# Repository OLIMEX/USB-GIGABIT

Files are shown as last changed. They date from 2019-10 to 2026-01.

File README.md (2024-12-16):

# USB-GIGABIT
USB 1.1, USB 2.0, USB 3.0 to Ethernet 10/100/1000Mbit converter

Transfer troughput is up to 950Mbits/s when connected to USB 3.0 ports and GbE network.

Using the A20 OLinuXino boards and USB 2.0 host the speed is: upload 319 Mbit, download 295 Mbit.

## Commands
    iperf3 -c 192.168.0.xxx -p 2001 -t 3
    iperf3 -c 192.168.0.xxx -p 2001 -t 3 -R
    
## Empirical Test Results

Using the commands listed above and good grade Gigabit equipment.

| Board | Upload | Download |
|---|---|---|
| PC USB 3.0 | 933 Mbits/sec | 942 Mbits/sec |
| PC USB 2.0 | 290 Mbits/sec | 312 Mbits/sec |
| A20-MICRO  | 319 Mbits/sec | 295 Mbits/sec |

# License
- Hardware is released under CERN OHL v1.2 license
- Documentation is released under CC BY-SA 4.0 license

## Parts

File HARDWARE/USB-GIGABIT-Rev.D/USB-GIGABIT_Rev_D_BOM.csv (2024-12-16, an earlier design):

Id | Designator | Footprint | Quantity | Designation | Supplier and ref
1 | C2,C3,C4,C10,C11,C14,C15,C16,C18,C19,C20,C21,C22,C24,C25,C26,C27,C1 | C_0402_5MIL_DWS | 18 | 100nF/10V/X5R /20%/0402
2 | C5 | C_0805_5MIL_DWS | 1 | 100nF/50V/Y5V/20%
3 | C6 | C_0402_5MIL_DWS | 1 | NA
4 | C7,C8 | C_0402_5MIL_DWS | 2 | 39pF/C0G/50VDC/0402
5 | C9 | C_1206_5MIL_DWS_ISO | 1 | 1nF/2000V/10%/X7R/1206
6 | C12,C17 | C_0603_5MIL_DWS | 2 | 2.2uF/X5R/6.3V/10%/0603
7 | FB1 | L_0805_5MIL_DWS | 1 | 600OHM/2A/UPZ2012E-601-2R0TF/0805
8 | R2,R3 | R_0402_5MIL_DWS | 2 | 22R/0402
9 | R4 | R_0805_5MIL_DWS | 1 | 10R/0805
10 | R5,R6,R10,R13,R14 | R_0402_5MIL_DWS | 5 | NA
11 | R9,R11 | R_0402_5MIL_DWS | 2 | 2.2K/0402
12 | U2 | SO-8 | 1 | NA(93LC46)
13 |  | LOGO_RECYCLEBIN_1 | 1
14 | U3 | QFN48-6x6mm-OLIMEX_V2 | 1 | RTL8153VC-CG
15 | X1 | Oscillator-18.432MHz-3.2x2.5mm | 1 | 25MHz/20ppm/20pF/4P/3225
16 | R1,R7 | R_0402_5MIL_DWS | 2 | 1K/0402
17 | R8 | R_0402_5MIL_DWS | 1 | 2.49K/1%/0402
18 | L1 | CD32 | 1 | 2.2uH/NRS3015T2R2MNGH
19 | R12,R15 | R_0402_5MIL_DWS | 2 | 1.1K/1%/0402
20 | U4 | SOT-23-5 | 1 | SY8089AAAC
21 | FID1,FID2 | Fiducial1x3 | 2 | Fiducial
22 | FID4,FID3 | Fiducial1x3_Paste | 2 | Fiducial
23 |  | LOGO_OPENHARDWARE_8x8 | 1
24 |  | LOGO_PBFREE | 1
25 | LAN1 | TM211Q01FM22 | 1 | TM211Q01FM22(LPJG16402AQNL)
26 | USB1 | USB3_A_MALE | 1 | USB1065
27 | Sign_CE | CE_Sign | 1 | CE_Sign
28 | Sign_Antistatic | Sign_Antistatic | 1 | Sign_Antistatic
29 | Logo_OLIMEX_TB | Logo_OLIMEX_TB | 1 | Logo_OLIMEX_TB
30 | Sign_RoHS_1 | Sign_RoHS_1 | 1 | Sign_RoHS_1

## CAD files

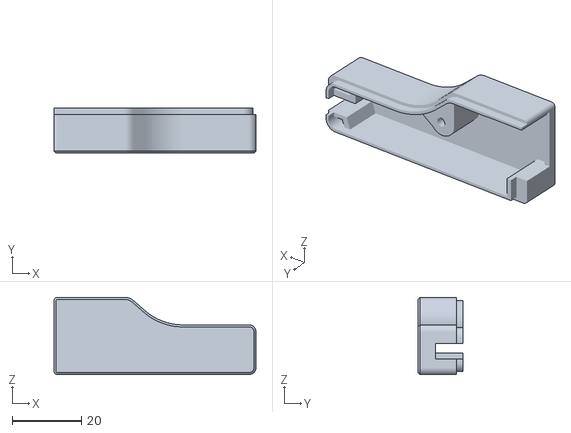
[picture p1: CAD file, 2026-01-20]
HARDWARE/BOXED-3D-design/part1.stl
58.4 x 13.1 x 22.3

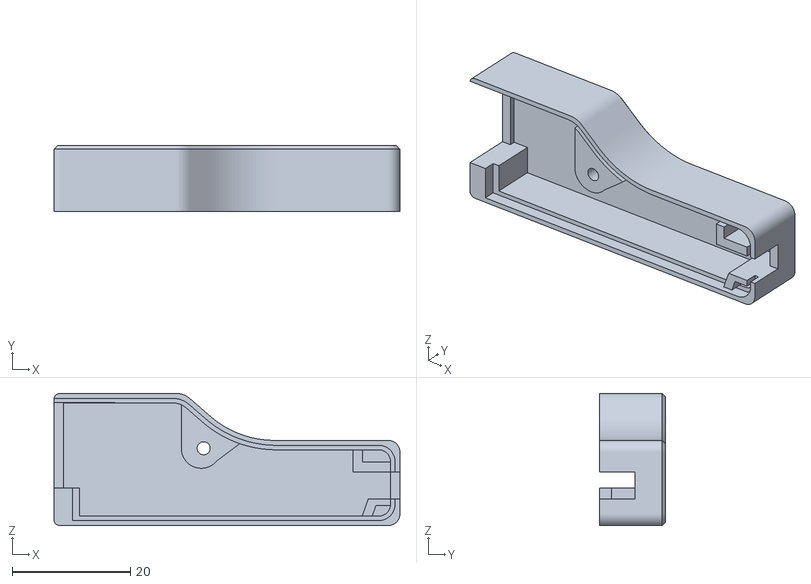
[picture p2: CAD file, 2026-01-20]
HARDWARE/BOXED-3D-design/part2.stl
58.4 x 11.1 x 22.3

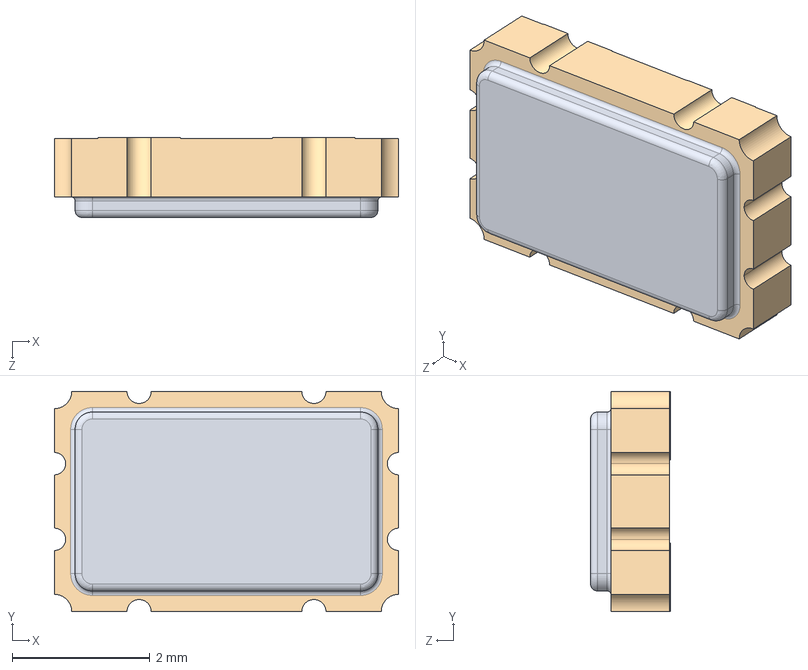
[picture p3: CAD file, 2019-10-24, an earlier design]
HARDWARE/USB-GIGABIT-Rev.C/3d/QSG5032.step
5.00 x 3.20 x 1.16 mm

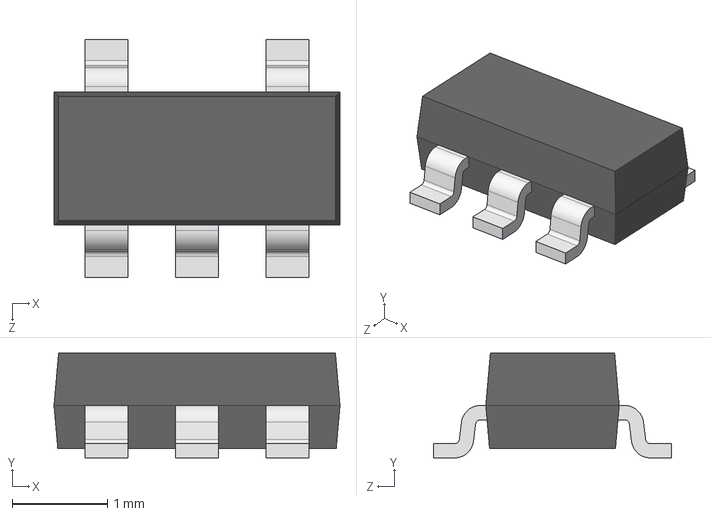
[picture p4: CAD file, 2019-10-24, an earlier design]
HARDWARE/USB-GIGABIT-Rev.C/3d/SOT-23-5.step
3.00 x 1.10 x 2.50 mm

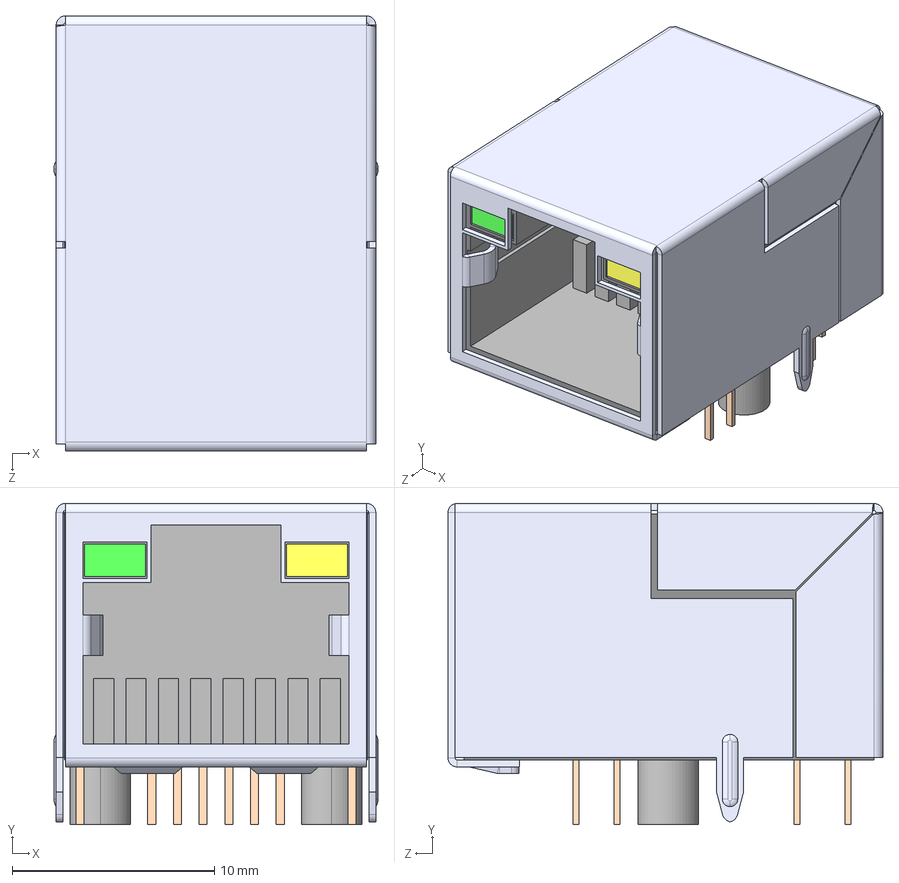
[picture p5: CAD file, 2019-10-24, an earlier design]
HARDWARE/USB-GIGABIT-Rev.C/3d/RJ45_10P_TJ3009.STEP
16.0 x 15.9 x 21.5 mm

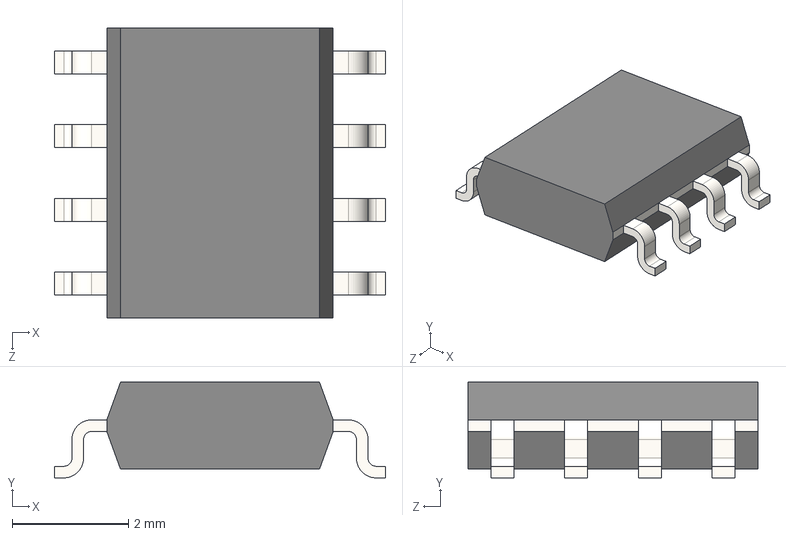
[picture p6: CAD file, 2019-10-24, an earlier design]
HARDWARE/USB-GIGABIT-Rev.C/3d/SL08.step
5.70 x 1.65 x 5.00 mm

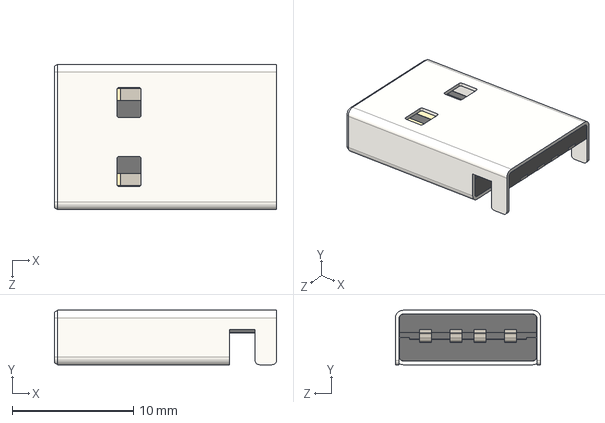
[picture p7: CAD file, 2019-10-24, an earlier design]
HARDWARE/USB-GIGABIT-Rev.C/3d/USB-A-MALE.step
18.3 x 4.50 x 12.0 mm

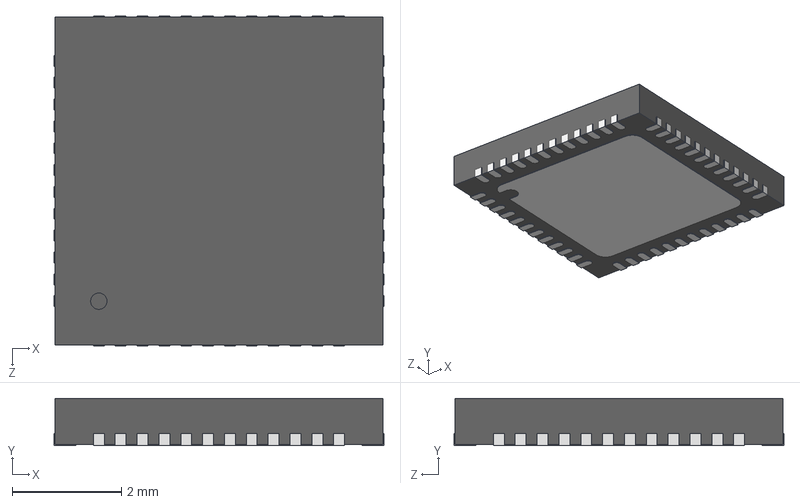
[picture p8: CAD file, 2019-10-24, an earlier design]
HARDWARE/USB-GIGABIT-Rev.C/3d/QFN48_6x6.step
6.04 x 0.868 x 6.04 mm

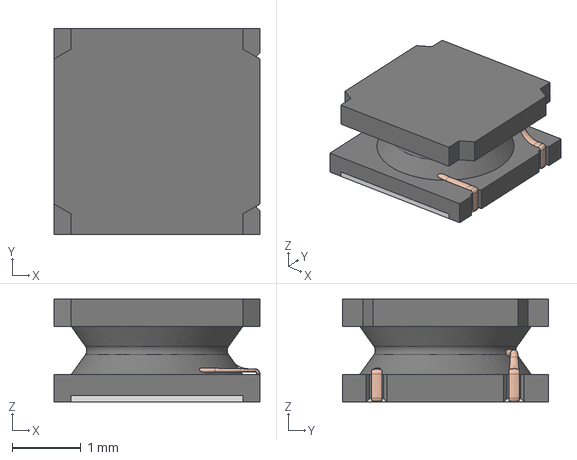
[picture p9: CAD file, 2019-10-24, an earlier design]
HARDWARE/USB-GIGABIT-Rev.C/3d/L-CD32_shielded.step
3.00 x 3.00 x 1.50 mm

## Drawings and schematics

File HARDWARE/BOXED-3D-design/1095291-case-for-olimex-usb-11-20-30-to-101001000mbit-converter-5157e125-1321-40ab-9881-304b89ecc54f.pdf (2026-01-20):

## Case for Olimex USB 1.1, 2.0, 3.0 to

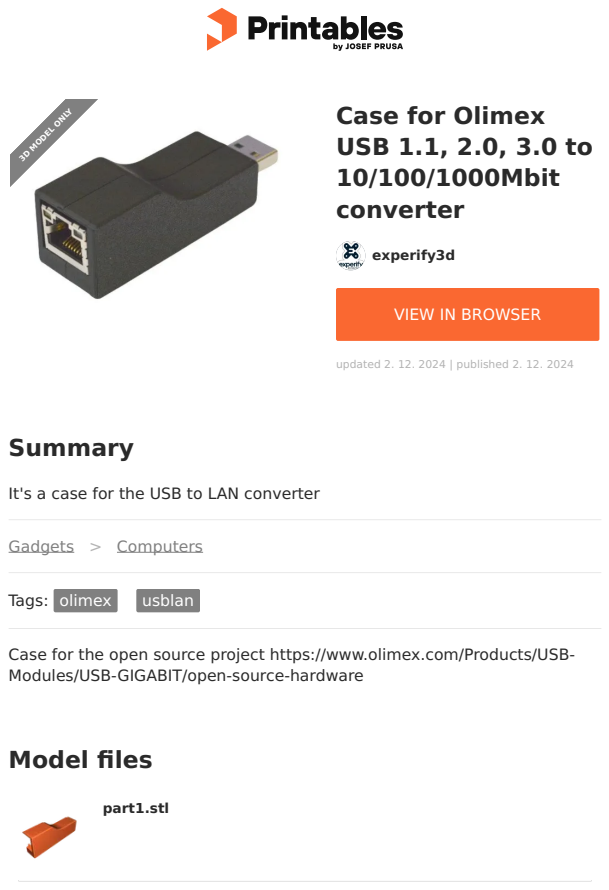
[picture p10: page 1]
Model files; Summary; Gadgets > Computers; Tags: olimex; usblan; experify3d; 10/100/1000Mbit converter; updated 2. 12. 2024 | published 2. 12. 2024; part1.stl; 3D MODEL ONLY

VIEW IN BROWSER (https://printables.com/model/1095291-case-for-olimex-usb-11-20-30-to-101001000mbit-conv)

It's a case for the USB to LAN converter

Case for the open source project https://www.olimex.com/Products/USB-
Modules/USB-GIGABIT/open-source-hardware

## License

This work is licensed under a
Creative Commons (4.0 International License)

Attribution (http://creativecommons.org/licenses/by/4.0/)

✖ | Sharing without ATTRIBUTION
✔ | Remix Culture allowed
✔ | Commercial Use
✔ | Free Cultural Works
✔ | Meets Open Definition

part2.stl

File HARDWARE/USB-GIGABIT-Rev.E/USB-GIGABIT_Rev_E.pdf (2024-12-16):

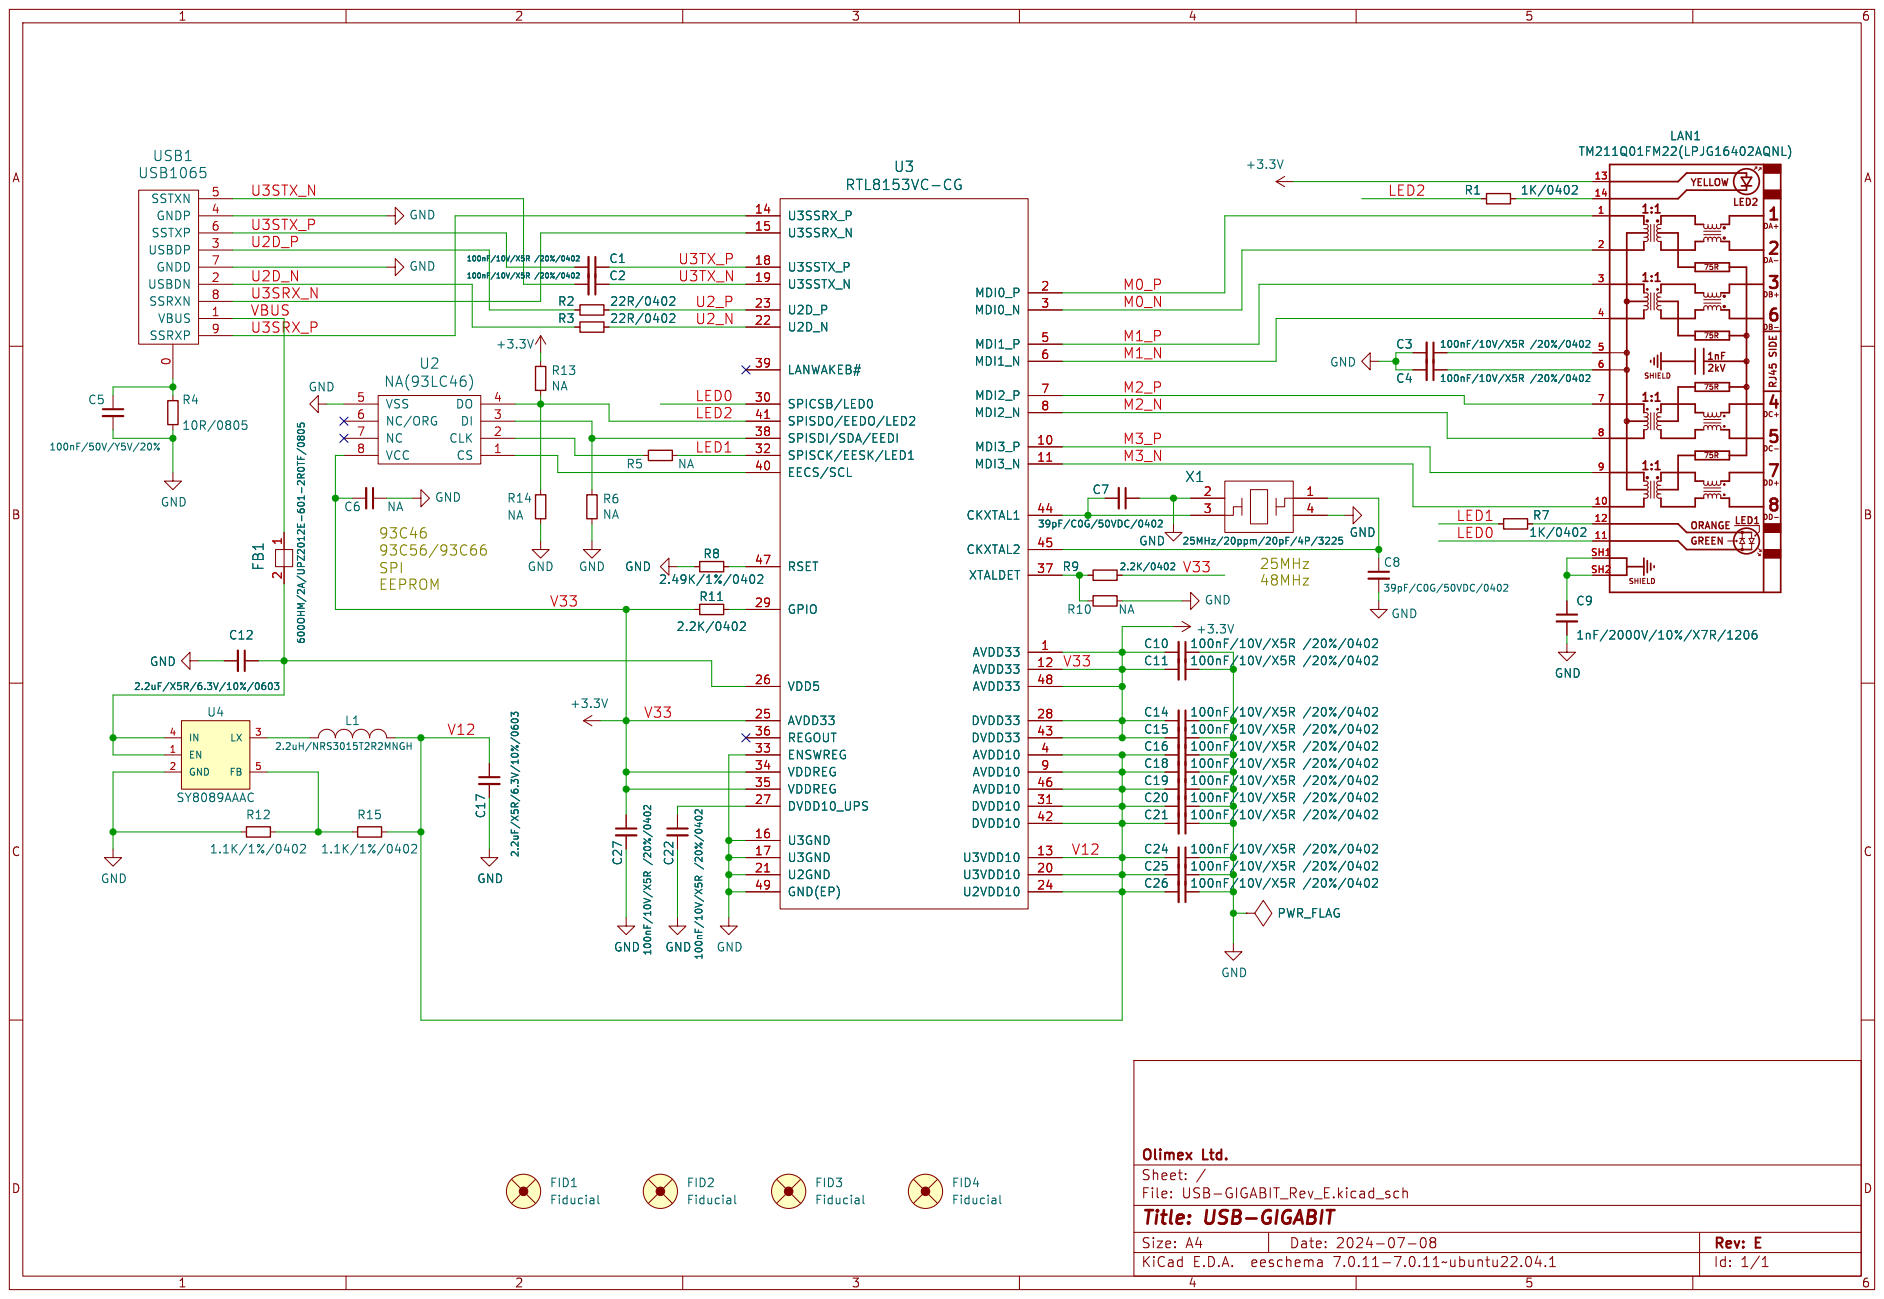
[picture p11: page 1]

0 VBUS 1 USBDN 2 USBDP 3 GNDP 4 SSTXN 5 SSTXP 6 GNDD 7 SSRXN 8 SSRXP 9 USB1
USB1065R4

DA+ DA- DB+ DB- DC+ DC- DD+ DD- GREEN

1 2FB1 600OHM/2A/UPZ2012E-601-2R0TF/0805 GND GND GND GND R14 NA GND

Id: 1/1 Title: USB-GIGABIT

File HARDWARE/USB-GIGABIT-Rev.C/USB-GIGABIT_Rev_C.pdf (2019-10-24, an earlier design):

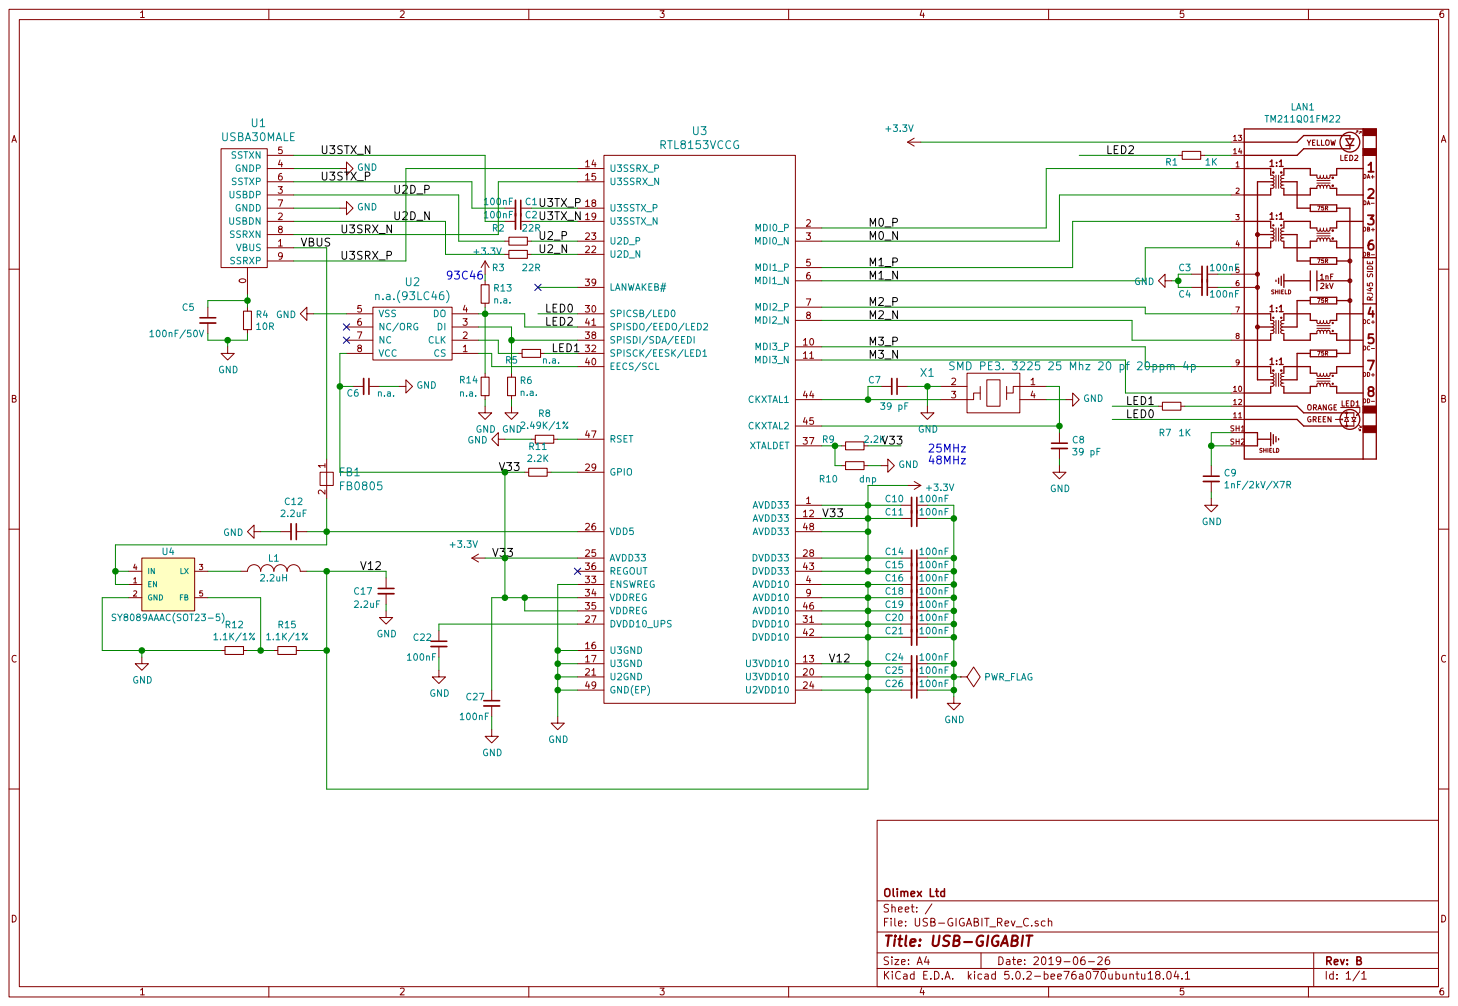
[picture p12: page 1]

DA+ DA- DB+ DB- DC+ DC- DD+ DD- GREEN

0 VBUS 1 USBDN 2 USBDP 3 GNDP 4 SSTXN 5 SSTXP 6 GNDD 7 SSRXN 8 SSRXP 9 U1 USBA30MALE

File: USB-GIGABIT_Rev_C.sch Sheet: / Olimex Ltd

Id: 1/1 Title: USB-GIGABIT

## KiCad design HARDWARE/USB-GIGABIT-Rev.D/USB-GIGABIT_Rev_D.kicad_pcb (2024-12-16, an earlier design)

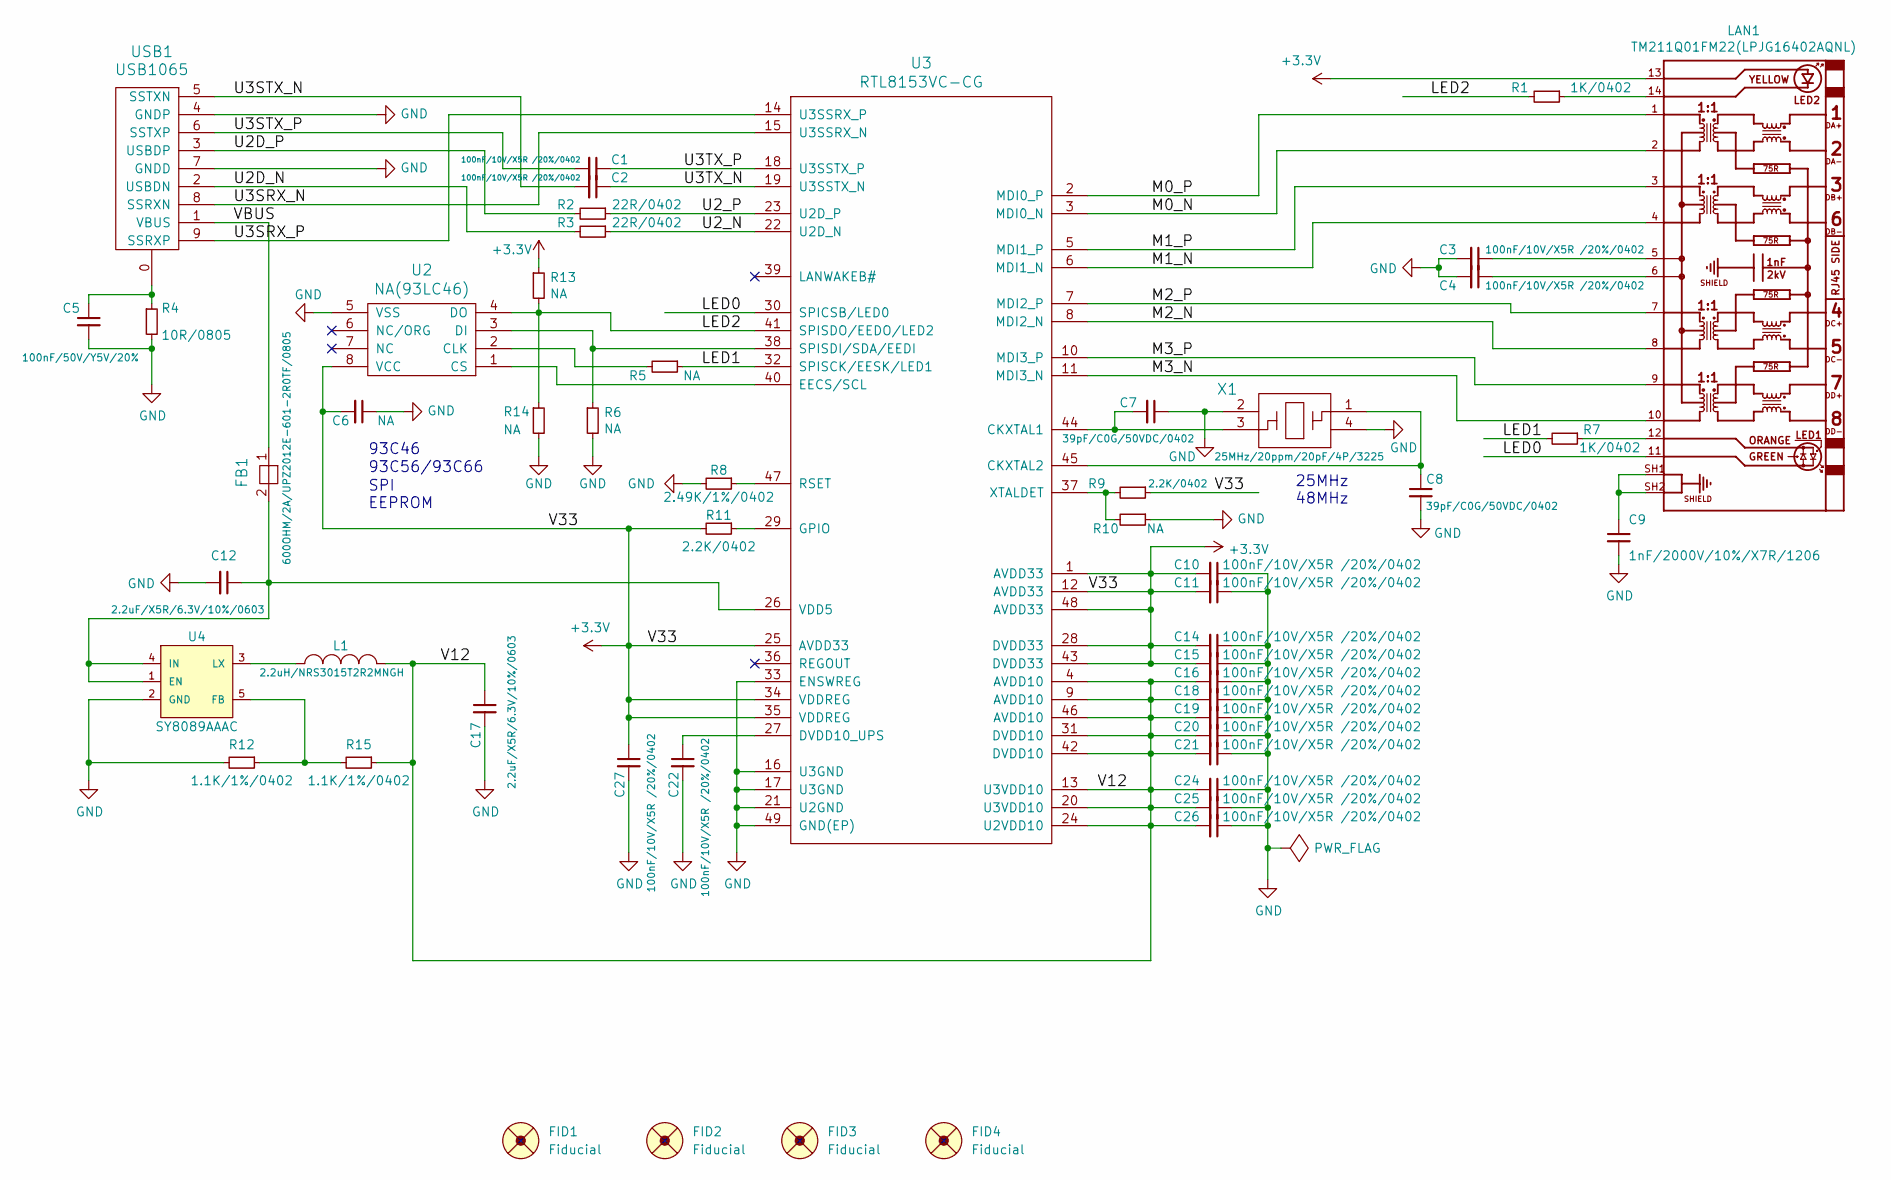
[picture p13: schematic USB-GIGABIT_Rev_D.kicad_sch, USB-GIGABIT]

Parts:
C1, C2, C3, C4, C10, C11, C14, C15, C16, C18, C19, C20, C21, C22, C24, C25, C26, C27: 100nF/10V/X5R /20%/0402; C_0402_5MIL_DWS
C5: 100nF/50V/Y5V/20%; C_0805_5MIL_DWS
C6: NA; C_0402_5MIL_DWS
C7, C8: 39pF/C0G/50VDC/0402; C_0402_5MIL_DWS
C9: 1nF/2000V/10%/X7R/1206; C_1206_5MIL_DWS_ISO
C12, C17: 2.2uF/X5R/6.3V/10%/0603; C_0603_5MIL_DWS
FB1: 600OHM/2A/UPZ2012E-601-2R0TF/0805; L_0805_5MIL_DWS
FID1, FID2: Fiducial; Fiducial1x3
FID3, FID4: Fiducial; Fiducial1x3_Paste
L1: 2.2uH/NRS3015T2R2MNGH; CD32
LAN1: TM211Q01FM22(LPJG16402AQNL); TM211Q01FM22
R1, R7: 1K/0402; R_0402_5MIL_DWS
R2, R3: 22R/0402; R_0402_5MIL_DWS
R4: 10R/0805; R_0805_5MIL_DWS
R5, R6, R10, R13, R14: NA; R_0402_5MIL_DWS
R8: 2.49K/1%/0402; R_0402_5MIL_DWS
R9, R11: 2.2K/0402; R_0402_5MIL_DWS
R12, R15: 1.1K/1%/0402; R_0402_5MIL_DWS
U2: NA(93LC46); SO-8
U3: RTL8153VC-CG; QFN48-6x6mm-OLIMEX_V2
U4: SY8089AAAC; SOT-23-5
USB1: USB1065; USB3_A_MALE
X1: 25MHz/20ppm/20pF/4P/3225; Oscillator-18.432MHz-3.2x2.5mm

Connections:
+3V3: C6.2, C10.2, C11.2, C14.2, C15.2, C27.1, LAN1.13, R9.1, R11.2, R13.1, U2.8 (VCC), U3.1 (AVDD33), U3.12 (AVDD33), U3.25 (AVDD33), U3.28 (DVDD33), U3.34 (VDDREG), U3.35 (VDDREG), U3.43 (DVDD33), U3.48 (AVDD33)
/LED0: LAN1.11, U3.30 (SPICSB/LED0)
/LED1: R5.1, R7.2, U3.32 (SPISCK/EESK/LED1)
/LED2: R1.2, R13.2, R14.1, U2.4 (DO), U3.41 (SPISDO/EEDO/LED2)
/M0_N: LAN1.2, U3.3 (MDI0_N)
/M0_P: LAN1.1, U3.2 (MDI0_P)
/M1_N: LAN1.4, U3.6 (MDI1_N)
/M1_P: LAN1.3, U3.5 (MDI1_P)
/M2_N: LAN1.8, U3.8 (MDI2_N)
/M2_P: LAN1.7, U3.7 (MDI2_P)
/M3_N: LAN1.10, U3.11 (MDI3_N)
/M3_P: LAN1.9, U3.10 (MDI3_P)
/U2D_N: R3.2, USB1.2 (USBDN)
/U2D_P: R2.2, USB1.3 (USBDP)
/U2_N: R3.1, U3.22 (U2D_N)
/U2_P: R2.1, U3.23 (U2D_P)
/U3SRX_N: U3.15 (U3SSRX_N), USB1.8 (SSRXN)
/U3SRX_P: U3.14 (U3SSRX_P), USB1.9 (SSRXP)
/U3STX_N: C2.2, USB1.5 (SSTXN)
/U3STX_P: C1.2, USB1.6 (SSTXP)
/U3TX_N: C2.1, U3.19 (U3SSTX_N)
/U3TX_P: C1.1, U3.18 (U3SSTX_P)
/V12: C16.2, C17.1, C18.2, C19.2, C20.2, C21.2, C24.2, C25.2, C26.2, L1.2, R15.1, U3.4 (AVDD10), U3.9 (AVDD10), U3.13 (U3VDD10), U3.20 (U3VDD10), U3.24 (U2VDD10), U3.31 (DVDD10), U3.42 (DVDD10), U3.46 (AVDD10)
/VBUS: FB1.1, USB1.1 (VBUS)
GND: C3.2, C4.2, C5.2, C6.1, C7.1, C8.2, C9.2, C10.1, C11.1, C12.2, C14.1, C15.1, C16.1, C17.2, C18.1, C19.1, C20.1, C21.1, C22.2, C24.1, C25.1, C26.1, C27.2, R4.2, R6.2, R8.2, R10.1, R12.2, R14.2, U2.5 (VSS), U3.16 (U3GND), U3.17 (U3GND), U3.21 (U2GND), U3.33 (ENSWREG), U3.49 (GND(EP)), U4.2 (GND), USB1.4 (GNDP), USB1.7 (GNDD), X1.2, X1.4
unnamed: C5.1, R4.1, USB1.0
unnamed: C9.1, LAN1.SH1, LAN1.SH2
unnamed: C3.1, LAN1.5
unnamed: C4.1, LAN1.6
unnamed: LAN1.12, R7.1
unnamed: LAN1.14, R1.1
unnamed: R5.2, U2.2 (CLK)
unnamed: U2.1 (CS), U3.40 (EECS/SCL)
unnamed: R6.1, U2.3 (DI), U3.38 (SPISDI/SDA/EEDI)
unnamed: C7.2, U3.44 (CKXTAL1), X1.3
unnamed: C8.1, U3.45 (CKXTAL2), X1.1
unnamed: C22.1, U3.27 (DVDD10_UPS)
unnamed: R11.1, U3.29 (GPIO)
unnamed: R8.1, U3.47 (RSET)
unnamed: C12.1, FB1.2, U3.26 (VDD5), U4.1 (EN), U4.4 (IN)
unnamed: R9.2, R10.2, U3.37 (XTALDET)
unnamed: R12.1, R15.2, U4.5 (FB)
unnamed: L1.1, U4.3 (LX)

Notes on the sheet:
93C56/93C66
25MHz 48MHz
SPI EEPROM
93C46

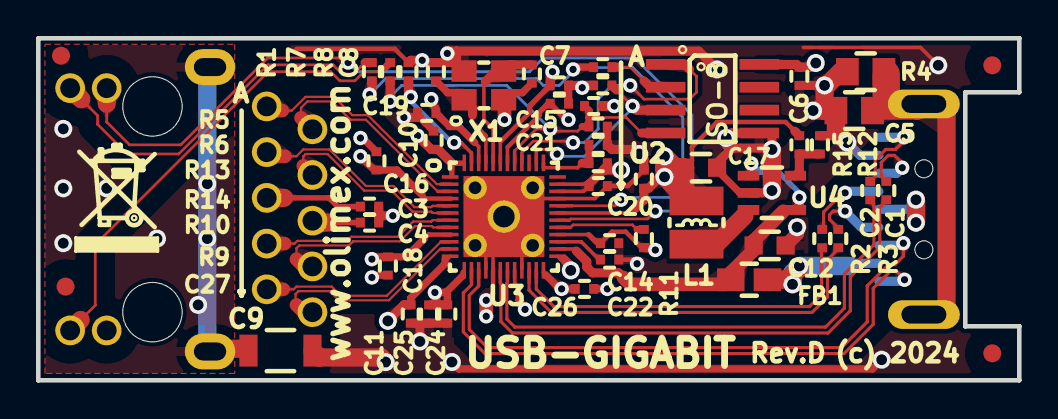
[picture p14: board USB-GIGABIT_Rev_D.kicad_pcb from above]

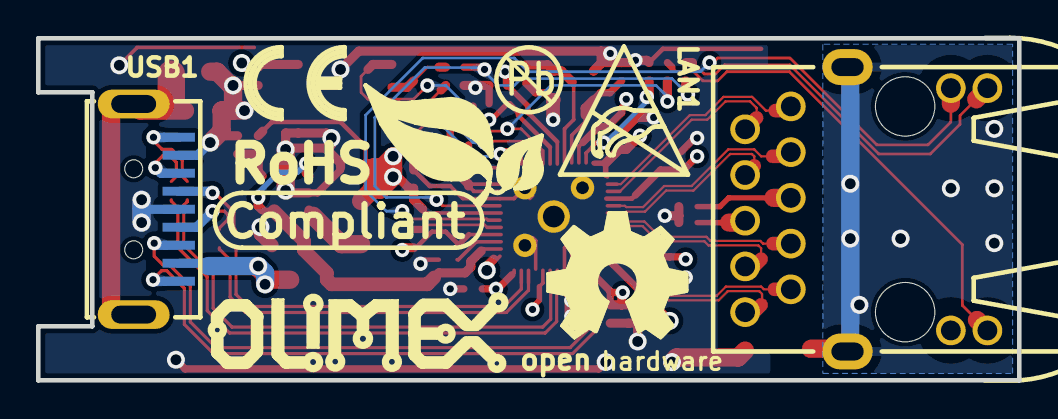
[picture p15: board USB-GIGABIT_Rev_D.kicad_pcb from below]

Board: 4 copper layers, 54.5 x 19.0 mm, 56 parts (6 on the bottom side), 43 nets.

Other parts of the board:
Logo_OLIMEX_TB: Logo_OLIMEX_TB
Sign_Antistatic: Sign_Antistatic
Sign_CE: CE_Sign
Sign_RoHS_1: Sign_RoHS_1

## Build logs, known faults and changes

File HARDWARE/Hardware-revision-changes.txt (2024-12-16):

Rev.E
=====
1. Added second GND on pin 16.
2. The resize from revision D was reverted, it was deemed unnecessary after the plastic box was made.

Rev.D
=====
1. Remade the whole board in KiCad 7 and all components moved to the top side. All packages and routing re-done.
2. Board made a bit larger to make the USB stronger.

Rev.C
=====
Initial board release.

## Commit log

2019-10-24 initial upload cad files
    [L-CD32_shielded.step, QFN48_6x6.step, QSG5032.step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]
2024-12-16 Update
    Added latest hardware revisions.
    [USB-GIGABIT_Rev_D-B_Cu.gbr, USB-GIGABIT_Rev_D-B_Mask.gbr, USB-GIGABIT_Rev_D-B_Paste.gbr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]
2026-01-20 Update
    3D files
    [part1.stl, part2.stl]

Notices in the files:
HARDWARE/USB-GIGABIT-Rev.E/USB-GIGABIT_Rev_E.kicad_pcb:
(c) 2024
